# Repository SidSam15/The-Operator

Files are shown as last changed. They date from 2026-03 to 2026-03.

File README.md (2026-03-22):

# The Operator

The Operator is a 4 key macropad with a rotary encoder, an OLED Display, and 16 LED's for underglow. It used KMK firmware.

This is my first macropad (and my first hardware project for Hack club ever!) and its purpose is to make the task of opening applications quicker, alongside looking cool. It works with hotkeys on my laptop to open applications like Fusion, Bambu Studio, VS Code, and Google at the click of a button, plus it controls volume and its LEDs with a Rotary Encoder. The OLED shows the last button clicked and it shows the on/off status of the LEDs. This project has helped me learn a lot, particularly in PCB design.

To use this, simply connect it to power via the USB-C on the XIAO 2040 and use like any other macropad.

## Features:
- Although only be visible once printed, the bottom layer uses clear filament to diffuse underglow and has a filleted bottom as tonot detract from the look of the black filament used in the top two layers.
- 128x32 OLED Display.
- EC11 Rotary encoder for volume and LED power. 
- 16 WS2812B RGB LEDs for underglow. Don't worry, their power is limited in firmware.
- 4 Keys.

## CAD Model:
Everything fits together using 4 M3 screws and heatset inserts. The screws go into the hols along the edges of the case

Case:



It has 3 separate printed pieces. The clear bottom where the PCB sits, the middle, and the top.

Full CAD:



Made in Fusion360.

## PCB:
This PCB was made in KiCad, and all the components of the silkscreen were downloaded from the web and manually added inside of KiCad.

Schematic

SchemFresh

PCB

PCB

I used MX_V1 for the keyswitch footprints, the generic footprint for the XIAO 2040, a 4-pin header for the OLED, the footprint from the guide for the rotary encoder, and the SK6812MINI-E for the LED footprints.

## Firmware Overview:
This hackpad uses KMK firmware for everything. 

- the rotary encoder changes volume. press to turn off LEDs.
- The 4 keys open applications by correlating with hotkeys on my laptop. Starting from the furthest left, they open Fusion, Bambu Studio, VS Code, and Google, respectivley. 
- The OLED shows the last key pressed and the LED on/off status.

In the future I really want to do more with the rotary encoder. I want to remove te volume feature and instead have it work with scripts on my laptop to preform a different function for each application (e.g, in VS turning would scroll, while pressing would run code, while in fusion, turning would do a 360 degree pan, while pressing would bring the veiw to home).

## BOM:
Everything needed to make this hackpad (aside from soldering iron and 3D printing things) can be found in the kit.

- 4x Cherry MX Switches
- 4x DSA Keycaps
- 4x M3x5x4 Heatset inserts
- 4x M3x16mm screws
- 16x WS2812B LEDs
- 1x 0.91" 128x32 OLED Display
- 1x EC11 Rotary Encoder
- 1x XIAO RP2040
- 1x Case (3 printed parts, one in clear filament the rest in black)

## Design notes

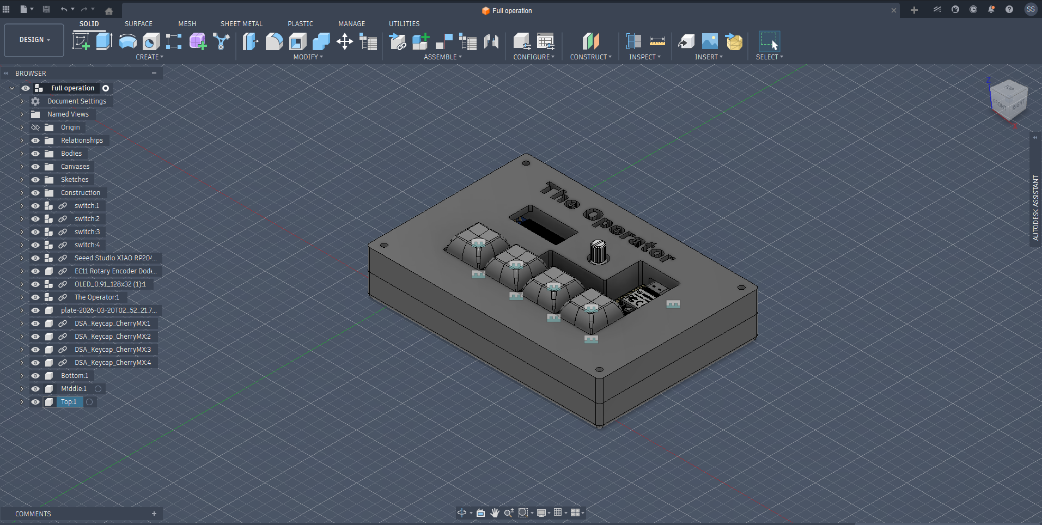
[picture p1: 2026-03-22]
Media Assets/image.png

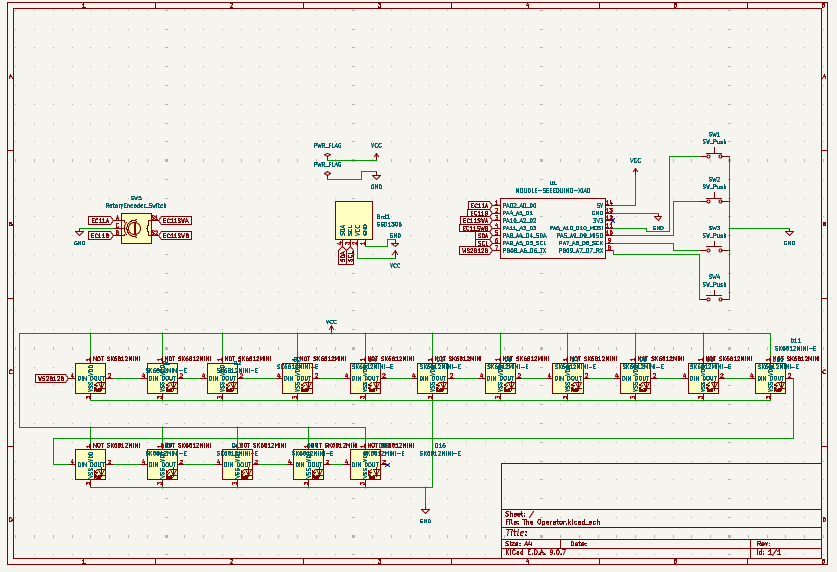
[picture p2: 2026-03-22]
Media Assets/SchemFresh.png

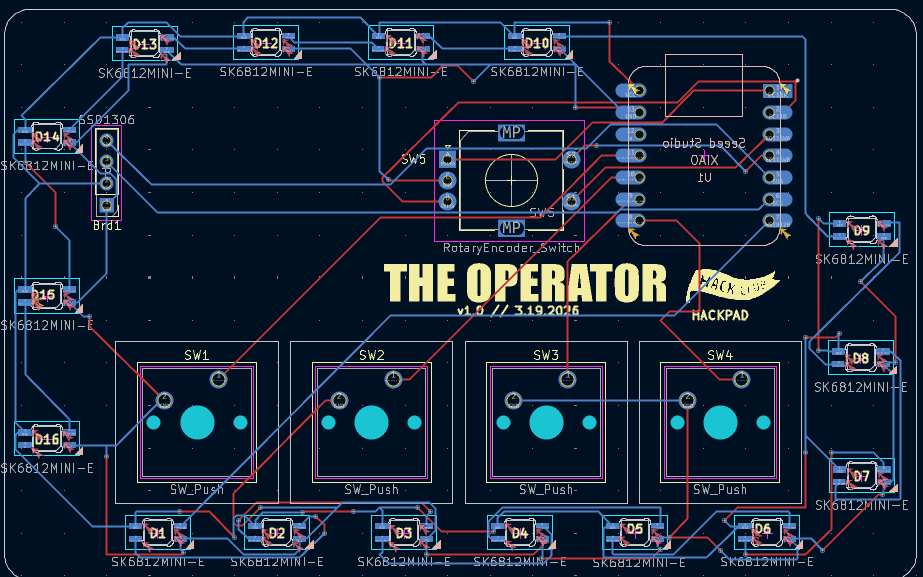
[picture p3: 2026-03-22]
Media Assets/PCB.png

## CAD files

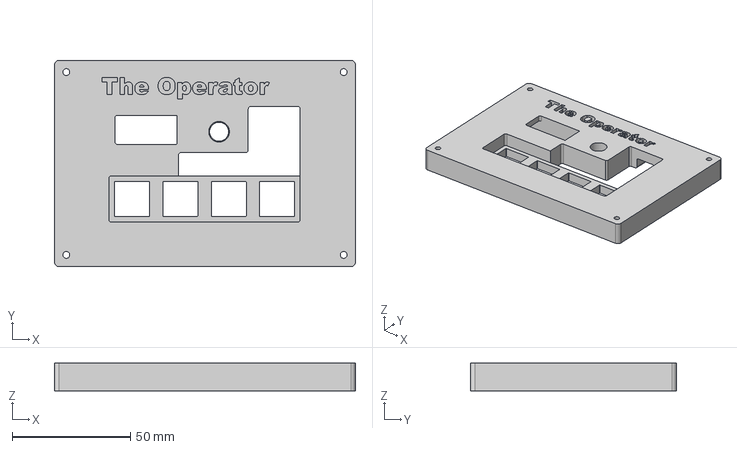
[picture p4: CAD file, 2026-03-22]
CAD/Top.step
127.4 x 87.4 x 11.7 mm

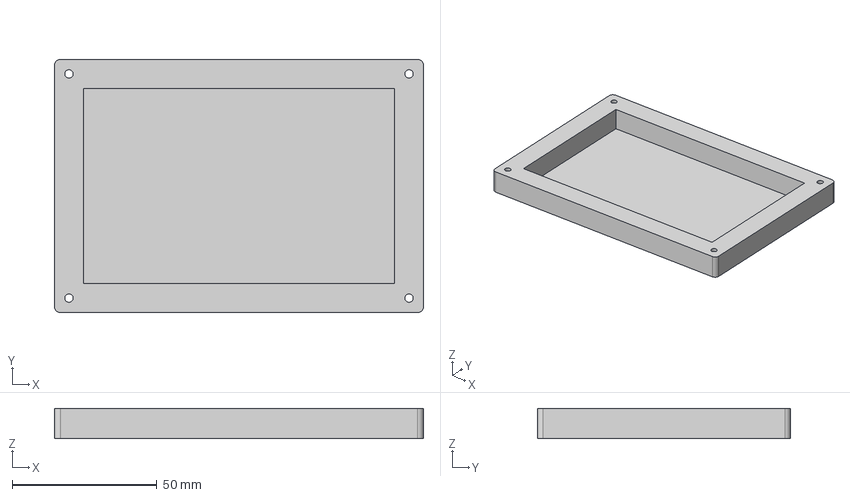
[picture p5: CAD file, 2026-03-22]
CAD/Middle.step
127.4 x 87.4 x 10.5 mm

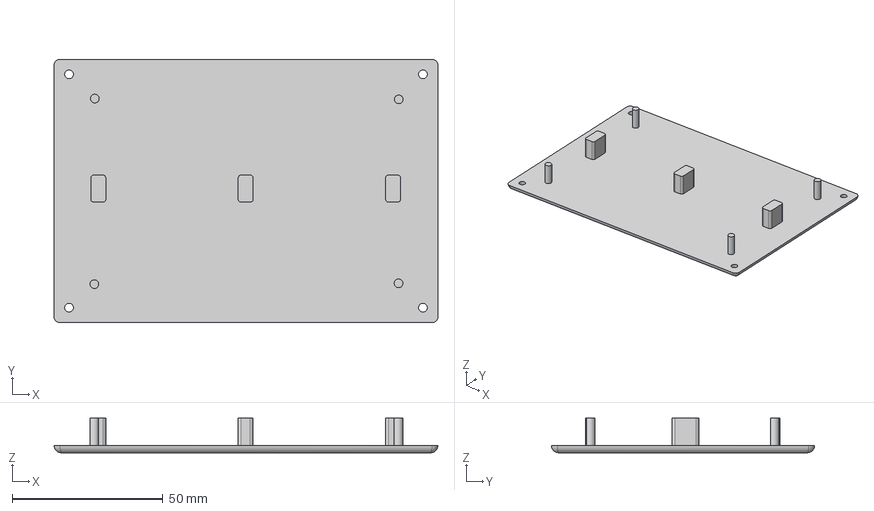
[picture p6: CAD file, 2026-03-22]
CAD/Bottom.step
127.4 x 87.4 x 11.5 mm

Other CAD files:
CAD/The Operator.f3z

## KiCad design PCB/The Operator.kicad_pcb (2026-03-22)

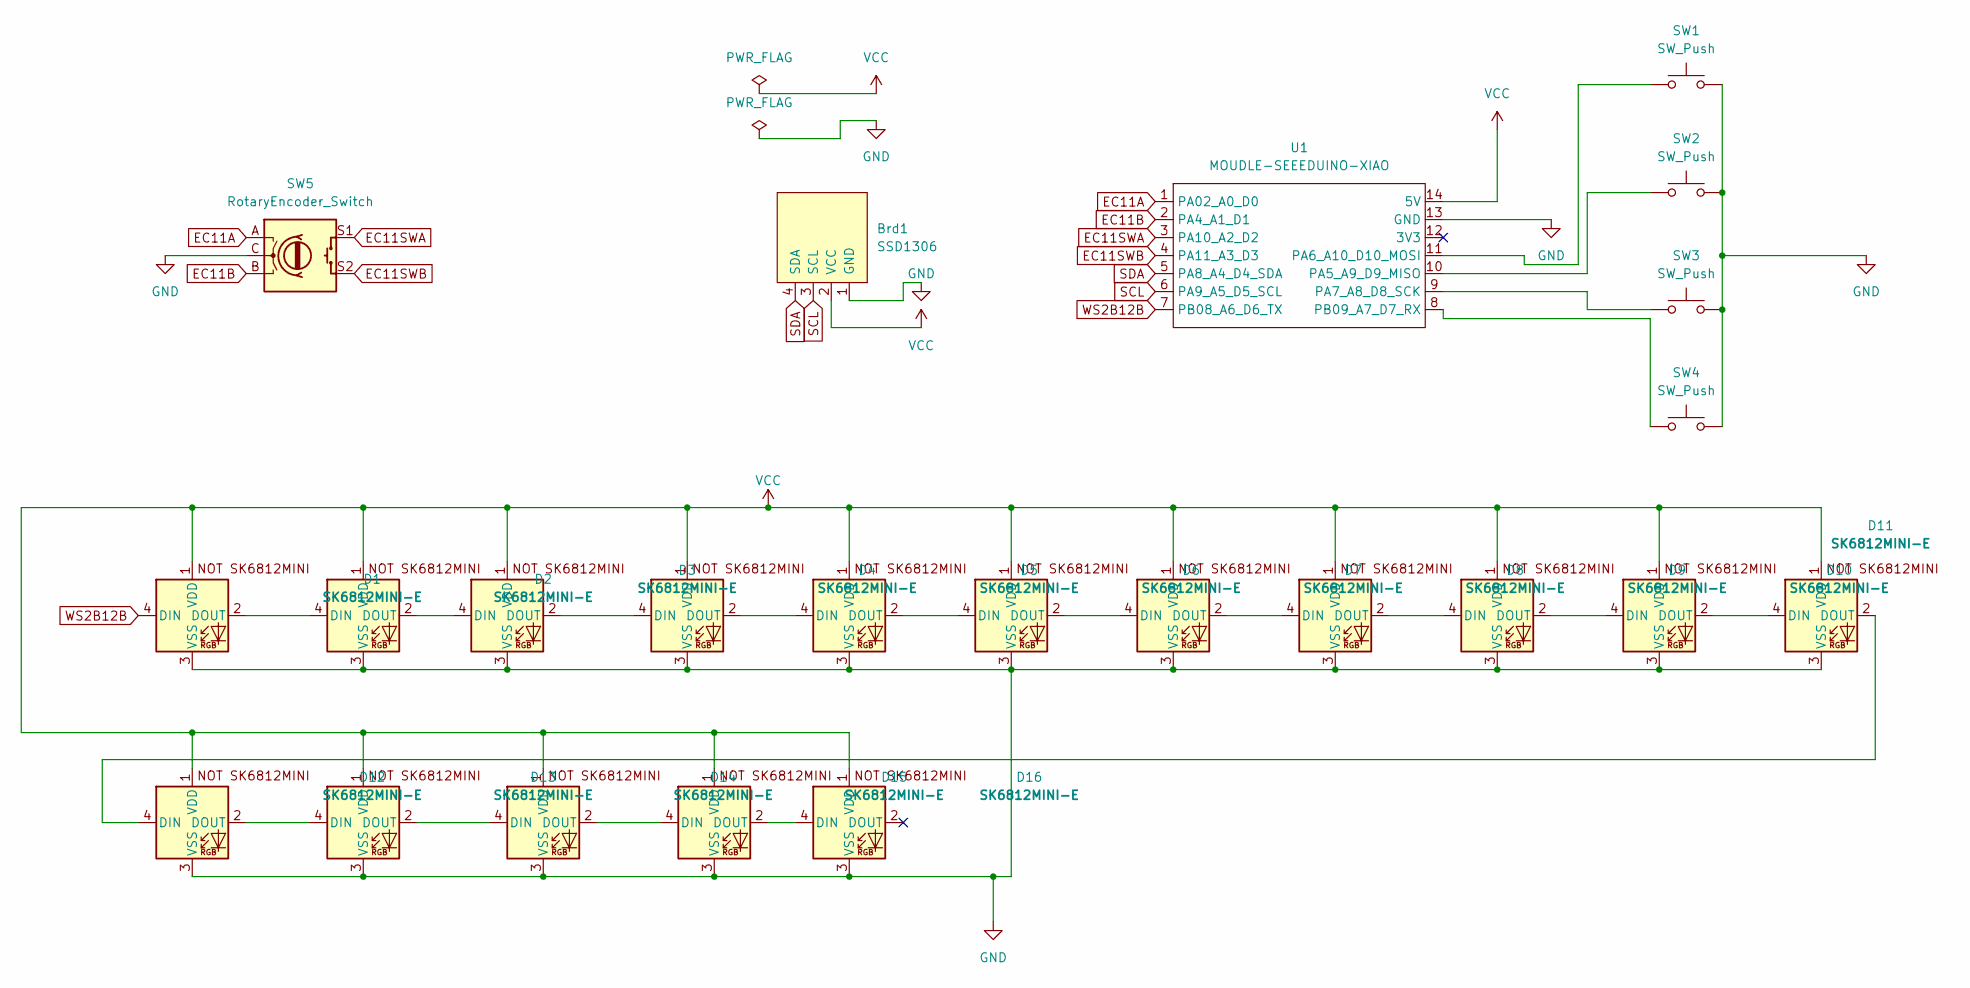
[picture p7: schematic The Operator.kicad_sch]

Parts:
Brd1: SSD1306; PinHeader_1x04_P2.54mm_Vertical
D1, D2, D3, D4, D5, D6, D7, D8, D9, D10, D11, D12, D13, D14, D15, D16: SK6812MINI-E; SK6812MINI-E_fixed
SW1, SW2, SW3, SW4: SW_Push; SW_Cherry_MX_1.00u_PCB
SW5: RotaryEncoder_Switch; RotaryEncoder_Alps_EC11E-Switch_Vertical_H20mm
U1: MOUDLE-SEEEDUINO-XIAO; XIAO-Generic-Hybrid-14P-2.54-21X17.8MM

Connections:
EC11A: SW5.A, U1.1 (PA02_A0_D0)
EC11B: SW5.B, U1.2 (PA4_A1_D1)
EC11SWA: SW5.S1, U1.3 (PA10_A2_D2)
EC11SWB: SW5.S2, U1.4 (PA11_A3_D3)
GND: Brd1.1 (GND), D1.3 (VSS), D2.3 (VSS), D3.3 (VSS), D4.3 (VSS), D5.3 (VSS), D6.3 (VSS), D7.3 (VSS), D8.3 (VSS), D9.3 (VSS), D10.3 (VSS), D11.3 (VSS), D12.3 (VSS), D13.3 (VSS), D14.3 (VSS), D15.3 (VSS), D16.3 (VSS), SW1.2, SW2.2, SW3.2, SW4.2, SW5.C, U1.13 (GND)
unnamed: D1.2 (DOUT), D2.4 (DIN)
unnamed: D2.2 (DOUT), D3.4 (DIN)
unnamed: D3.2 (DOUT), D4.4 (DIN)
unnamed: D4.2 (DOUT), D5.4 (DIN)
unnamed: D5.2 (DOUT), D6.4 (DIN)
unnamed: D6.2 (DOUT), D7.4 (DIN)
unnamed: D7.2 (DOUT), D8.4 (DIN)
unnamed: D8.2 (DOUT), D9.4 (DIN)
unnamed: D9.2 (DOUT), D10.4 (DIN)
unnamed: D10.2 (DOUT), D11.4 (DIN)
unnamed: D11.2 (DOUT), D12.4 (DIN)
unnamed: D12.2 (DOUT), D13.4 (DIN)
unnamed: D13.2 (DOUT), D14.4 (DIN)
unnamed: D14.2 (DOUT), D15.4 (DIN)
unnamed: D15.2 (DOUT), D16.4 (DIN)
unnamed: SW2.1, U1.10 (PA5_A9_D9_MISO)
unnamed: SW1.1, U1.11 (PA6_A10_D10_MOSI)
unnamed: SW3.1, U1.9 (PA7_A8_D8_SCK)
unnamed: SW4.1, U1.8 (PB09_A7_D7_RX)
SCL: Brd1.3 (SCL), U1.6 (PA9_A5_D5_SCL)
SDA: Brd1.4 (SDA), U1.5 (PA8_A4_D4_SDA)
VCC: Brd1.2 (VCC), D1.1 (VDD), D2.1 (VDD), D3.1 (VDD), D4.1 (VDD), D5.1 (VDD), D6.1 (VDD), D7.1 (VDD), D8.1 (VDD), D9.1 (VDD), D10.1 (VDD), D11.1 (VDD), D12.1 (VDD), D13.1 (VDD), D14.1 (VDD), D15.1 (VDD), D16.1 (VDD), U1.14 (5V)
WS2B12B: D1.4 (DIN), U1.7 (PB08_A6_D6_TX)

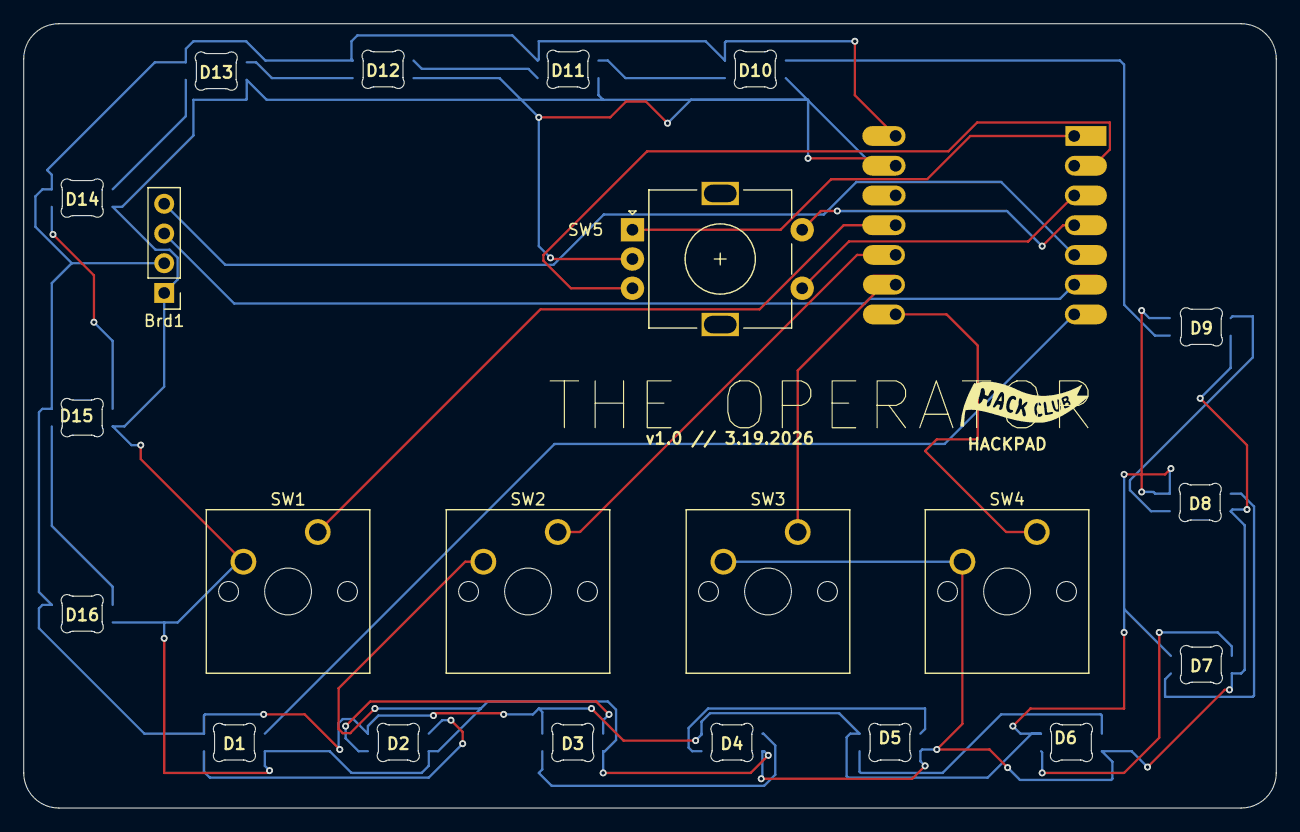
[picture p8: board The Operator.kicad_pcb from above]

Board: 2 copper layers, 107.0 x 67.0 mm, 23 parts (1 on the bottom side), 28 nets.

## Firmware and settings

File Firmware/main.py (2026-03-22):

import board
from kmk.kmk_keyboard import KMKKeyboard
from kmk.keys import KC
from kmk.modules.encoder import EncoderHandler
from kmk.extensions.rgb import RGB
from kmk.extensions.display.ssd1306 import SSD1306
from kmk.extensions.display import Display, TextEntry
keyboard = KMKKeyboard()
keyboard.keymap = [
    [
        KC.LCTRL(KC.LALT(KC.F)),  #Fusion
        KC.LCTRL(KC.LALT(KC.B)),  #Bambu Lab
        KC.LCTRL(KC.LALT(KC.V)),  #VS Code
        KC.LCTRL(KC.LALT(KC.G)),  #Google Chrome
    ],
]
keyboard.col_pins = (
    board.GP10,
    board.GP9,
    board.GP8,
    board.GP7,
)
keyboard.row_pins = ()
keyboard.diode_orientation = None
keyboard.internal_pullup = True
encoder_handler = EncoderHandler()
keyboard.modules.append(encoder_handler)
encoder_handler.pins = (
    (board.GP0, board.GP1, board.GP2),
)
led_on = True
def toggle_leds(key, keyboard, *args):
    global led_on
    if led_on:
        rgb.disable()
    else:
        rgb.enable()
    led_on = not led_on
    update_oled_status()
encoder_handler.map = [
    (
        (KC.VOLU, KC.VOLD), 
        toggle_leds    
    ),
]
rgb = RGB(
    pixel_pin=board.GP6,
    num_pixels=16,
)
rgb.brightness = 0.2
keyboard.extensions.append(rgb)
ssd1306_display = SSD1306(i2c=board.I2C())
key_text = TextEntry(text='Last key: None', x=0, y=0)
rgb_text = TextEntry(text='RGB: ON', x=0, y=10)
oled = Display(
    display=ssd1306_display,
    width=128,
    height=64,
    entries=[key_text, rgb_text],
)
keyboard.extensions.append(oled)
last_key = "None"
def update_oled_status(key=None):
    key_text.text = f"Last key: {last_key}"
    rgb_text.text = f"RGB: {'ON' if led_on else 'OFF'}"
    oled.text(f"Last key: {last_key}", 0, 0)
    oled.text(f"RGB: {'ON' if led_on else 'OFF'}", 0, 10)
    oled.show()
def on_key_press(key, keyboard, *args):
    update_oled_status(key)

keyboard.on_press.append(on_key_press)
if __name__ == "__main__":
    keyboard.go()

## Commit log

2026-03-22 fixed leds
    [The Operator.kicad_sch]
2026-03-22 Replace schematic and PCB images with new versions
    Updated schematic and PCB images in README.
2026-03-22 fixed oled
    [The Operator.kicad_pcb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]
2026-03-22 Update README with new PCB image
    Added a new PCB image to the README.
